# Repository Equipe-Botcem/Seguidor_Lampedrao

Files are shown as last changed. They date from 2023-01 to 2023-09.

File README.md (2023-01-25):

# Seguidor_Alpha
- Código utilizado para controle e envio de comandos do robô seguidor de linha da equipe de competição BOTCEM UFSC

## Guia de Instalação e execução:
1. Extrair o arquivo zip
2. Abrir pasta esp32_code com a extensão platform.io do VScode
3. Compilar arquivo e passa-ló para o ESP32 
4. Baixar aplicativo Line-follower.apk

## Pré-requisitos: 
1. Microcontrolador: esp32dev
2. Sistema operacional: Linux 20.04
3. IDE : Visual Studio Code
4. Framework: Arduino
	
## Autoria e constribuições:
- Esse projeto é autoria da equipe BOTCEM UFSC
	
## Fontes:
- Stack Overflow, c2022. Disponível em: <stackoverflow.com>. Acesso em: 18 de dezembro de 2022.

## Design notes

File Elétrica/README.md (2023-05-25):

# Documentação do Projeto Eletrônico do Seguidor de Linha Alpha

## 1. Projeto Elétrico

O projeto elétrico tem seu funcionamento separado em três parte: potência (alimentação) e controle.

### 1.1. Potência

O circuito de potência é composto pelos seguintes elementos:

- Bateria: LiPo 7,4V 2S 300mAh;
- Conversor de tensão Step Up: XL6009;
- Regulador de Tensão 5V: LM7805;
- Regulador de Tensão 3.3V: LM1117;
- Capacitores de Filtro: 0.22uF, 0.1uF e 10uF.
- Diodo;
- Switchs.

### 1.2. Controle

O circuito de controle é composto pelos seguintes elementos:

- Shield ESP32;
- Drivers IC: TB9051FTG Single Brushed;
- Encoders;
- Sensores de Refletância: QRE1117;
- Resistores: 47Kohns e 47ohns.

## 2. Projeto da PCB

O projeto da PCB foi desenvolvido no software KiCAD.
As dimensões da placa são: 119mm X 151mm X 1.6mm (Comprimento X Largura X Altura).
A placa é composta por duas camadas de trilhas, inferior e superior.

## 3. Medições

### 3.1. Corrente Consumida

Realizando a medição do Seguidor de Linha por uma fonte de tensão, pode-se obter as seguintes medidas de consumo:

- Ligado: 300mA;
- Velocidade Baixa: 600mA;
- Velocidade Alta: 1.5A. 

## 4. Melhorias

- Desenvolvimento de uma placa totalmente integrada.

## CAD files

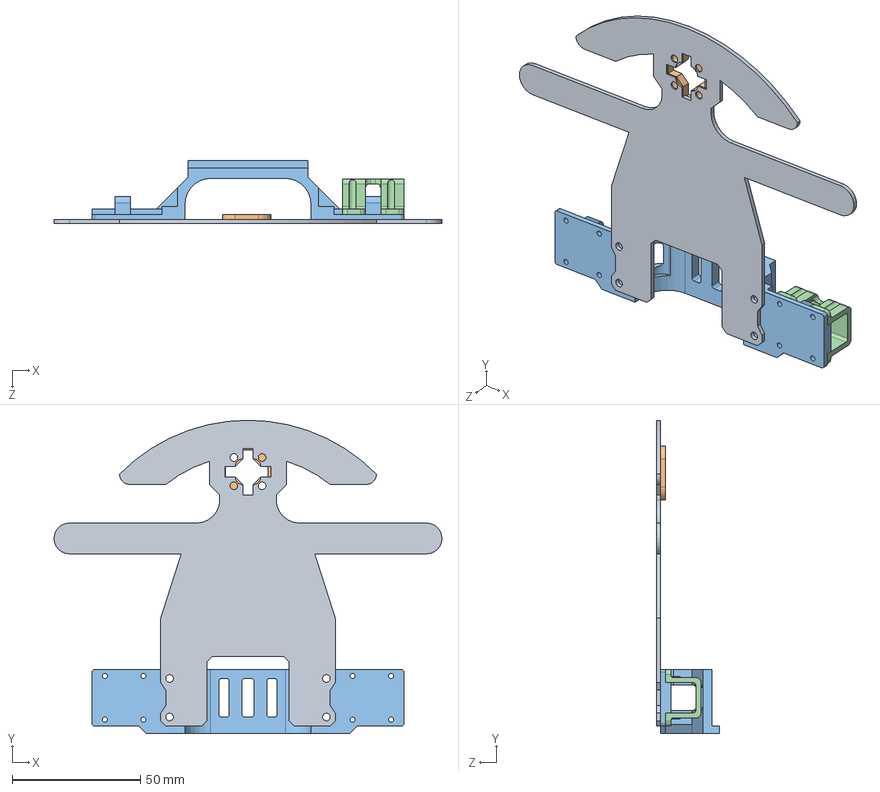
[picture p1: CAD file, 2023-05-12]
Estrutura/montagem.SLDASM
151.0 x 122.0 x 24.6 mm
placa
frontal
bateria
suporte

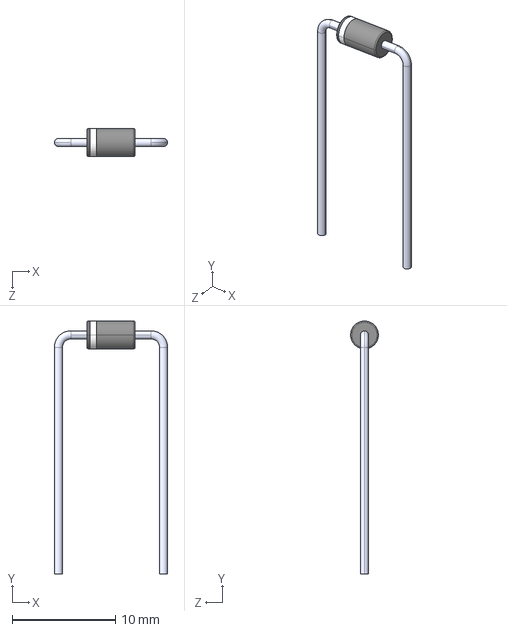
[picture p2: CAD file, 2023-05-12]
Elétrica/parts/1N5817G/1N5817G.step
10.9 x 24.5 x 2.69 mm

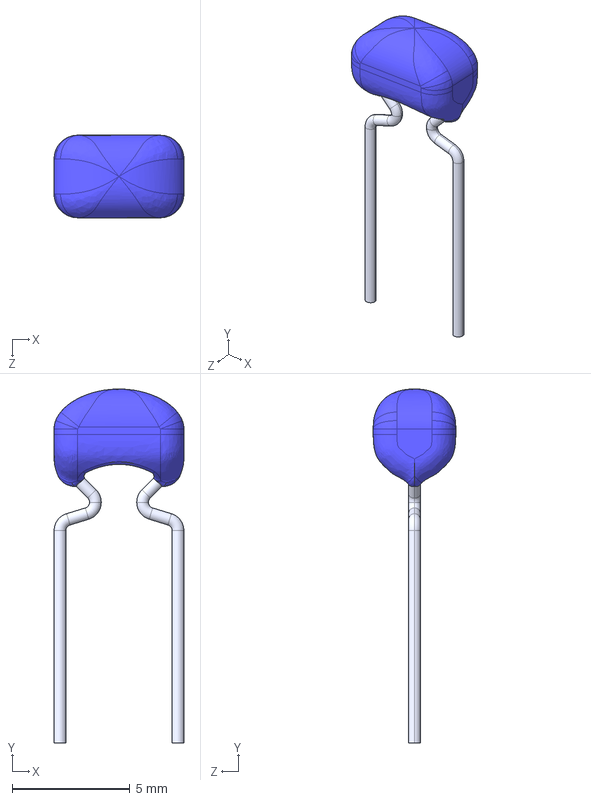
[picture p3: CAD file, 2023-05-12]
Elétrica/parts/FA16X7R2A224KNU00/FA16X7R2A224KNU00.step
5.50 x 15.0 x 3.50 mm

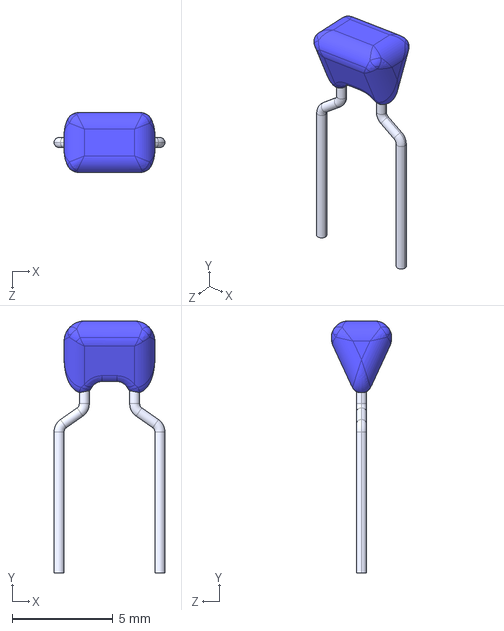
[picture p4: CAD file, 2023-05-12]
Elétrica/parts/FG24X7R1A106KRT00/FG24X7R1A106KRT00.step
5.50 x 12.5 x 3.00 mm

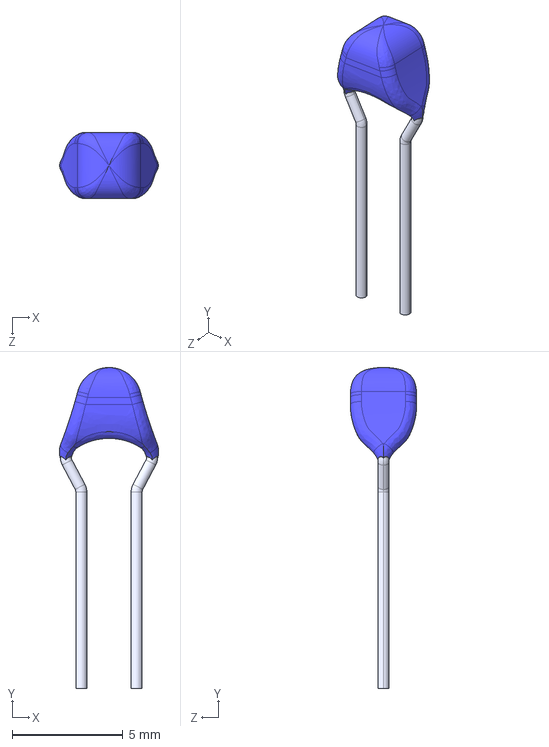
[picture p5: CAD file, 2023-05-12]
Elétrica/parts/FG24X7R2A104KNT06/FG24X7R2A104KNT06.step
4.48 x 14.5 x 3.00 mm

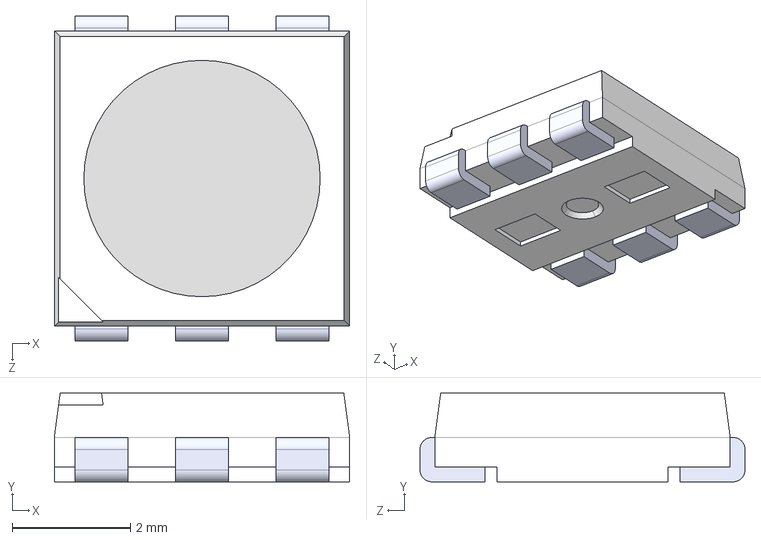
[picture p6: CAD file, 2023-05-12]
Elétrica/parts/IN-P55TATRGB/IN-P55TATRGB.step
5.00 x 1.50 x 5.50 mm

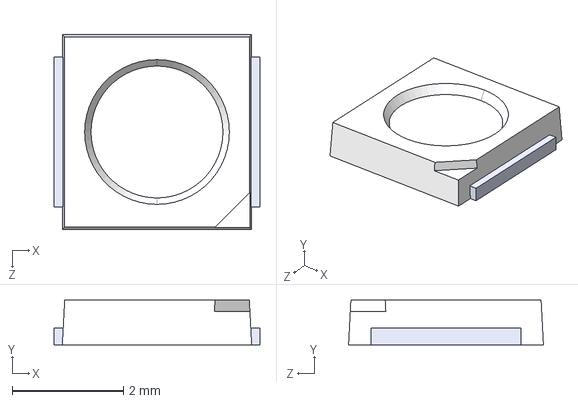
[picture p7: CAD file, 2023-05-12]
Elétrica/parts/L135-B475003500001/L135-B475003500001.step
3.70 x 0.8 x 3.50 mm

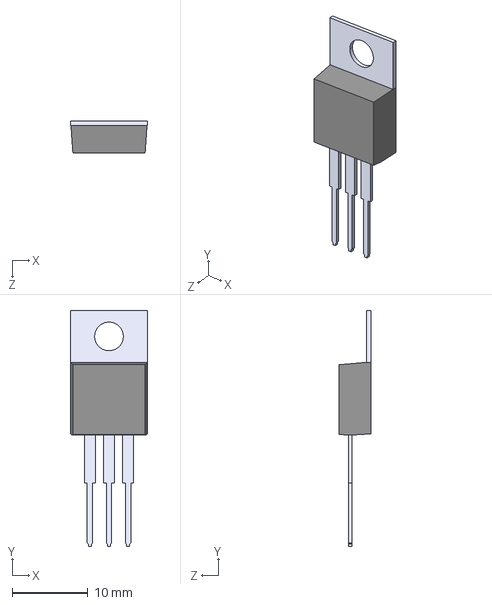
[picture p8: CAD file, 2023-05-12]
Elétrica/parts/LM1117T-3.3_NOPB/LM1117T-3.3_NOPB.step
10.2 x 31.2 x 4.20 mm

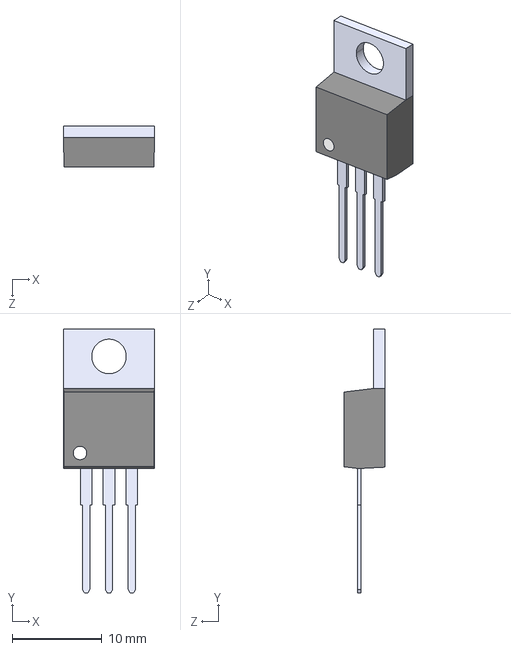
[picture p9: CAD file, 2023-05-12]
Elétrica/parts/LM7805/LM7805.step
10.2 x 29.3 x 4.57 mm

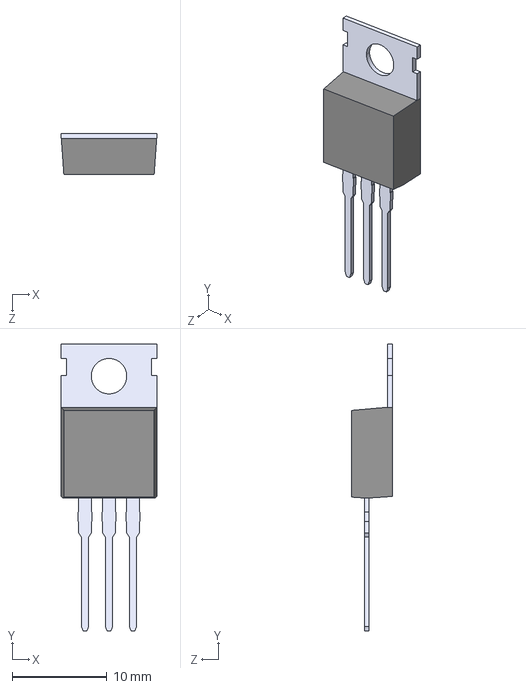
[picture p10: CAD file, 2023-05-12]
Elétrica/parts/LM7805CT_NOPB/LM7805CT_NOPB.step
10.2 x 30.3 x 4.35 mm

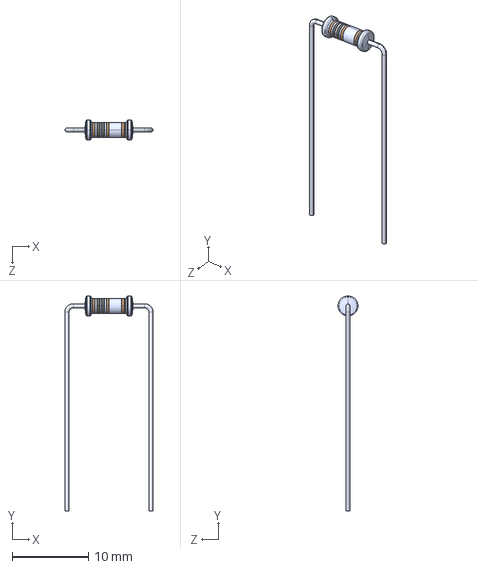
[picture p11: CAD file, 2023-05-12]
Elétrica/parts/MFR-25FBF52-61R9/MFR-25FBF52-61R9.step
11.6 x 28.1 x 2.60 mm

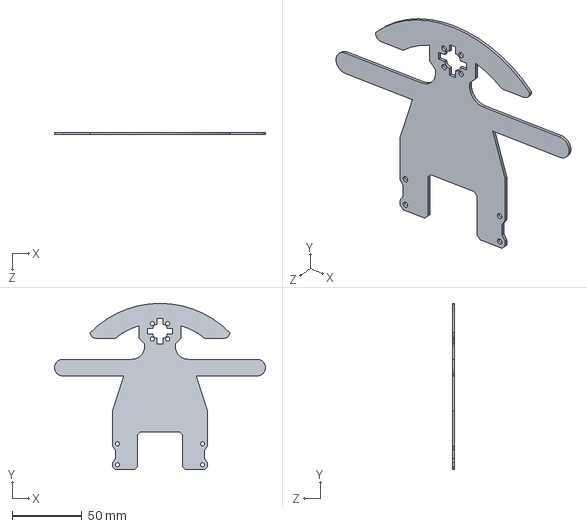
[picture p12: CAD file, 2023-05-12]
Estrutura/placa.SLDPRT
151.0 x 119.0 x 1.60 mm

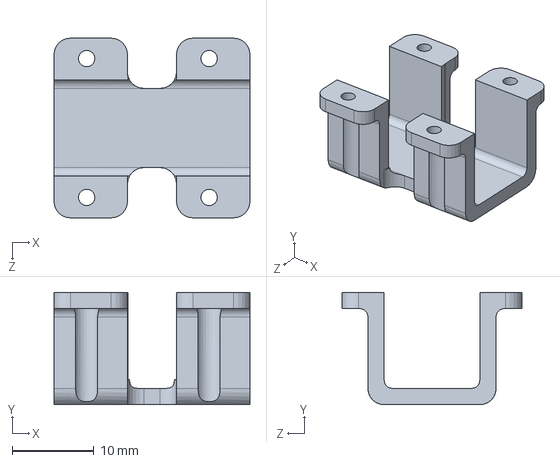
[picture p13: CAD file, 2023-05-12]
Estrutura/suporte.SLDPRT
24.0 x 13.8 x 22.0 mm

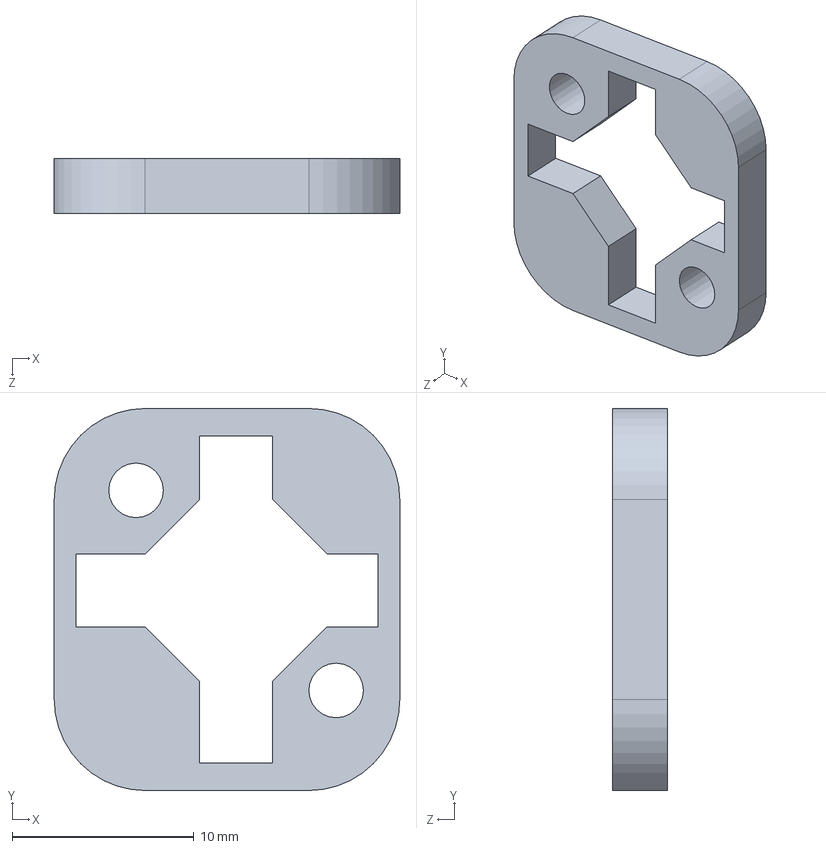
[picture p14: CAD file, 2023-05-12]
Estrutura/frontal.SLDPRT
19.0 x 21.0 x 3.00 mm

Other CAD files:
Estrutura/bateria.SLDPRT
Elétrica/parts/1622242-1/1622242-1.step

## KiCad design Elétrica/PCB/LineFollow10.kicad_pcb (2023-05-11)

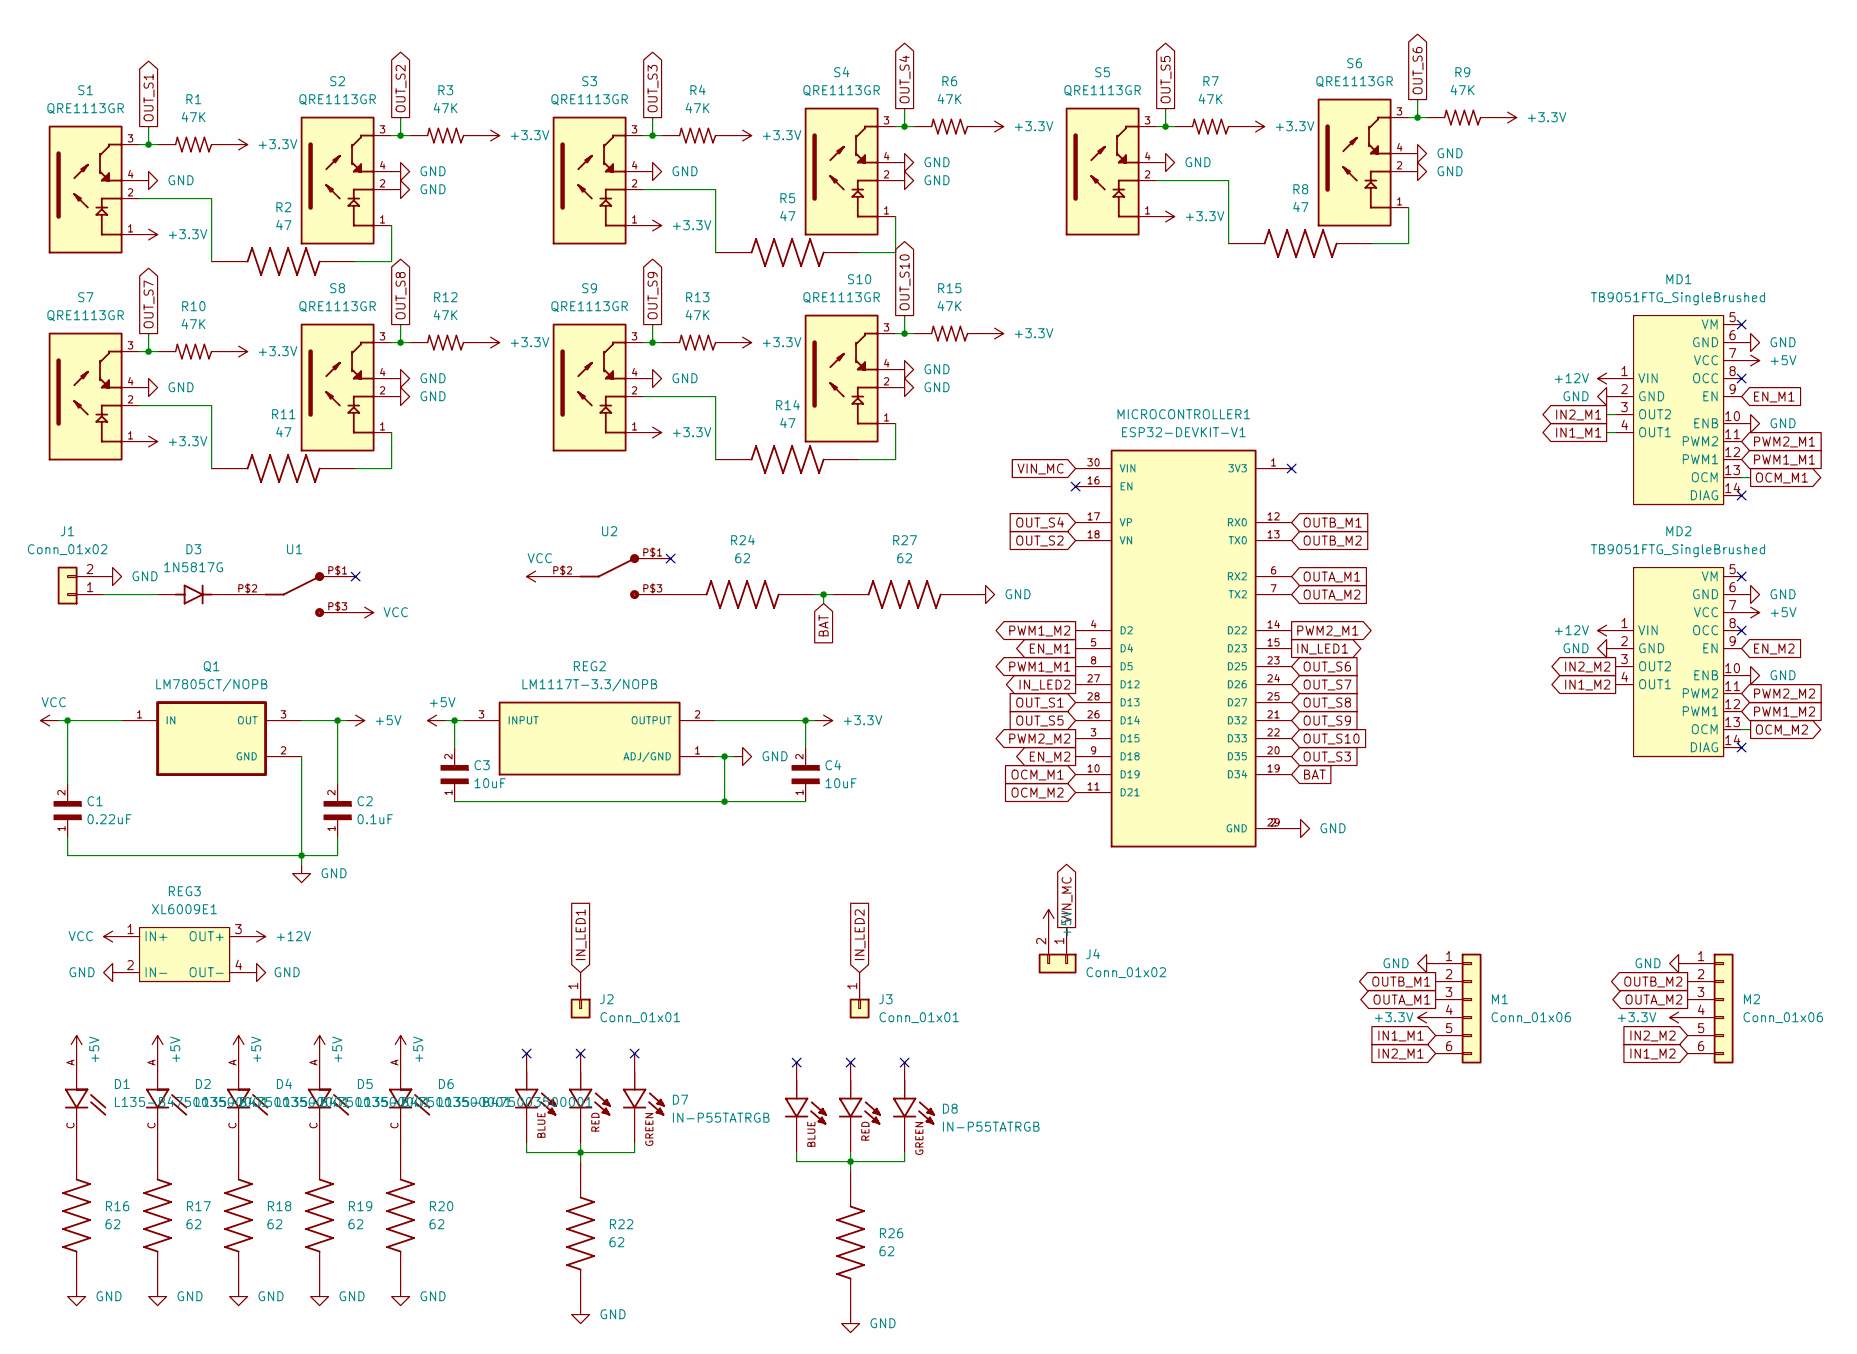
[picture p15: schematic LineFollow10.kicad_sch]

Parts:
C1: 0.22uF; CAPRB250W50L550T350H600; PARTREV 20200318
C2: 0.1uF; CAPRB500W50L450T300H550; PARTREV 20200310
C3, C4: 10uF; CAPRB500W50L450T300H550; PARTREV 20200310
D1, D2, D4, D5, D6: L135-B475003500001; LED_L135-B475003500001
D3: 1N5817G; DIOAD1036W78L470D235; PARTREV P2104
D7, D8: IN-P55TATRGB; LED_IN-P55TATRGB; PARTREV 1.0
J1: Conn_01x02; PinSocket_1x02_P2.54mm_Vertical
J2: Conn_01x01; SolderWire-0.1sqmm_1x01_D0.4mm_OD1mm
J3: Conn_01x01
J4: Conn_01x02
M1, M2: Conn_01x06; PinSocket_1x06_P2.54mm_Vertical
MD1, MD2: TB9051FTG_SingleBrushed
MICROCONTROLLER1: ESP32-DEVKIT-V1; MODULE_ESP32_DEVKIT_V1; PARTREV N/A
Q1: LM7805CT/NOPB; TO254P1054X470X2600-3; PARTREV LTR
R1, R3, R4, R6, R7, R9, R10, R12, R13, R15: 47K; RESAD640W45L370D200
R2, R5, R8, R11, R14: 47; RESAD716W44L360D186; PARTREV 11/16/2017
R16, R17, R18, R19, R20, R22, R24, R26, R27: 62; RESAD1100W55L680D260; PARTREV 201304
REG2: LM1117T-3.3/NOPB; TO254P1054X470X1955-3; PARTREV O
REG3: XL6009E1
S1, S2, S3, S4, S5, S6, S7, S8, S9, S10: QRE1113GR; SOIC180P460X187-4N; PARTREV 5
U1, U2: 0S102011MS2QN1

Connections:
+3.3V: C4.2, M1.4, M2.4, R1.1, R3.1, R4.1, R6.1, R7.1, R9.1, R10.1, R12.1, R13.1, R15.1, REG2.2 (OUTPUT), S1.1, S3.1, S5.1, S7.1, S9.1
+5V: C2.2, C3.2, D1.A, D2.A, D4.A, D5.A, D6.A, J4.2, MD1.7 (VCC), MD2.7 (VCC), Q1.3 (OUT), REG2.3 (INPUT)
+12V: MD1.1 (VIN), MD2.1 (VIN), REG3.3 (OUT+)
BAT: MICROCONTROLLER1.19 (D34), R24.1, R27.2
EN_M1: MD1.9 (EN), MICROCONTROLLER1.5 (D4)
EN_M2: MD2.9 (EN), MICROCONTROLLER1.9 (D18)
GND: C1.1, C2.1, C3.1, C4.1, J1.2, M1.1, M2.1, MD1.2 (GND), MD1.6 (GND), MD1.10 (ENB), MD2.2 (GND), MD2.6 (GND), MD2.10 (ENB), MICROCONTROLLER1.2 (GND), MICROCONTROLLER1.29 (GND), Q1.2 (GND), R16.1, R17.1, R18.1, R19.1, R20.1, R22.1, R26.1, R27.1, REG2.1 (ADJ/GND), REG3.2 (IN-), REG3.4 (OUT-), S1.4, S2.2, S2.4, S3.4, S4.2, S4.4, S5.4, S6.2, S6.4, S7.4, S8.2, S8.4, S9.4, S10.2, S10.4
IN1_M1: M1.5, MD1.4 (OUT1)
IN1_M2: M2.6, MD2.4 (OUT1)
IN2_M1: M1.6, MD1.3 (OUT2)
IN2_M2: M2.5, MD2.3 (OUT2)
IN_LED1: J2.1, MICROCONTROLLER1.15 (D23)
IN_LED2: J3.1, MICROCONTROLLER1.27 (D12)
unnamed: D1.C, R16.2
unnamed: D2.C, R17.2
unnamed: D3.A, J1.1
unnamed: D3.C, U1.P$2
unnamed: D4.C, R18.2
unnamed: D5.C, R19.2
unnamed: D6.C, R20.2
unnamed: D7.1, D7.2, D7.3, R22.2
unnamed: D8.1, D8.2, D8.3, R26.2
unnamed: R2.1, S1.2
unnamed: R2.2, S2.1
unnamed: R5.1, S3.2
unnamed: R5.2, S4.1
unnamed: R8.1, S5.2
unnamed: R8.2, S6.1
unnamed: R11.1, S7.2
unnamed: R11.2, S8.1
unnamed: R14.1, S9.2
unnamed: R14.2, S10.1
unnamed: R24.2, U2.P$3
OCM_M1: MD1.13 (OCM), MICROCONTROLLER1.10 (D19)
OCM_M2: MD2.13 (OCM), MICROCONTROLLER1.11 (D21)
OUTA_M1: M1.3, MICROCONTROLLER1.6 (RX2)
OUTA_M2: M2.3, MICROCONTROLLER1.7 (TX2)
OUTB_M1: M1.2, MICROCONTROLLER1.12 (RX0)
OUTB_M2: M2.2, MICROCONTROLLER1.13 (TX0)
OUT_S1: MICROCONTROLLER1.28 (D13), R1.2, S1.3
OUT_S2: MICROCONTROLLER1.18 (VN), R3.2, S2.3
OUT_S3: MICROCONTROLLER1.20 (D35), R4.2, S3.3
OUT_S4: MICROCONTROLLER1.17 (VP), R6.2, S4.3
OUT_S5: MICROCONTROLLER1.26 (D14), R7.2, S5.3
OUT_S6: MICROCONTROLLER1.23 (D25), R9.2, S6.3
OUT_S7: MICROCONTROLLER1.24 (D26), R10.2, S7.3
OUT_S8: MICROCONTROLLER1.25 (D27), R12.2, S8.3
OUT_S9: MICROCONTROLLER1.21 (D32), R13.2, S9.3
OUT_S10: MICROCONTROLLER1.22 (D33), R15.2, S10.3
PWM1_M1: MD1.12 (PWM1), MICROCONTROLLER1.8 (D5)
PWM1_M2: MD2.12 (PWM1), MICROCONTROLLER1.4 (D2)
PWM2_M1: MD1.11 (PWM2), MICROCONTROLLER1.14 (D22)
PWM2_M2: MD2.11 (PWM2), MICROCONTROLLER1.3 (D15)
VCC: C1.2, Q1.1 (IN), REG3.1 (IN+), U1.P$3, U2.P$2
VIN_MC: J4.1, MICROCONTROLLER1.30 (VIN)

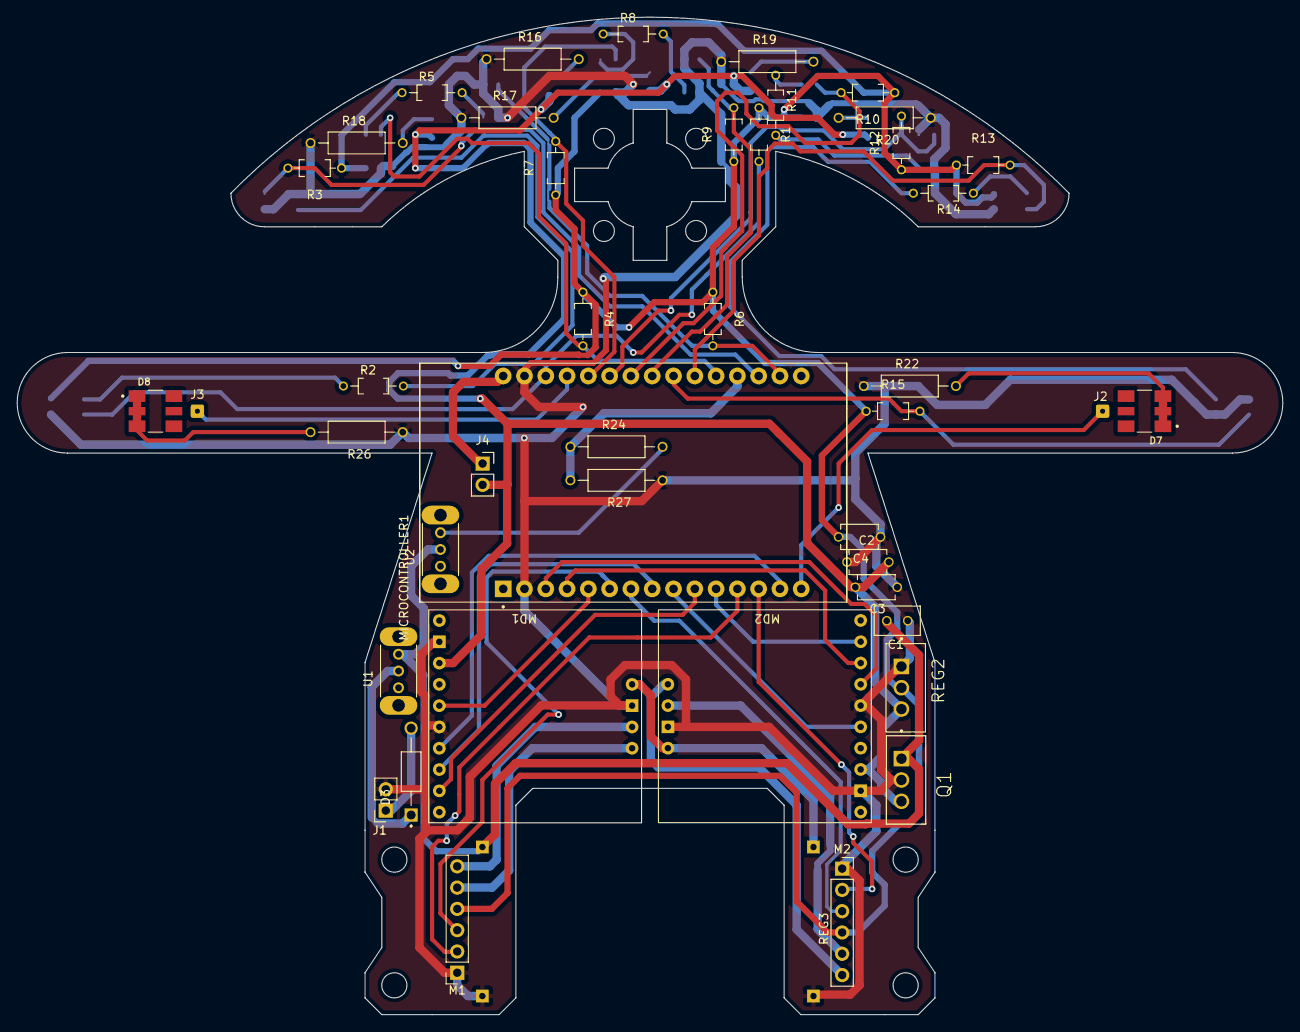
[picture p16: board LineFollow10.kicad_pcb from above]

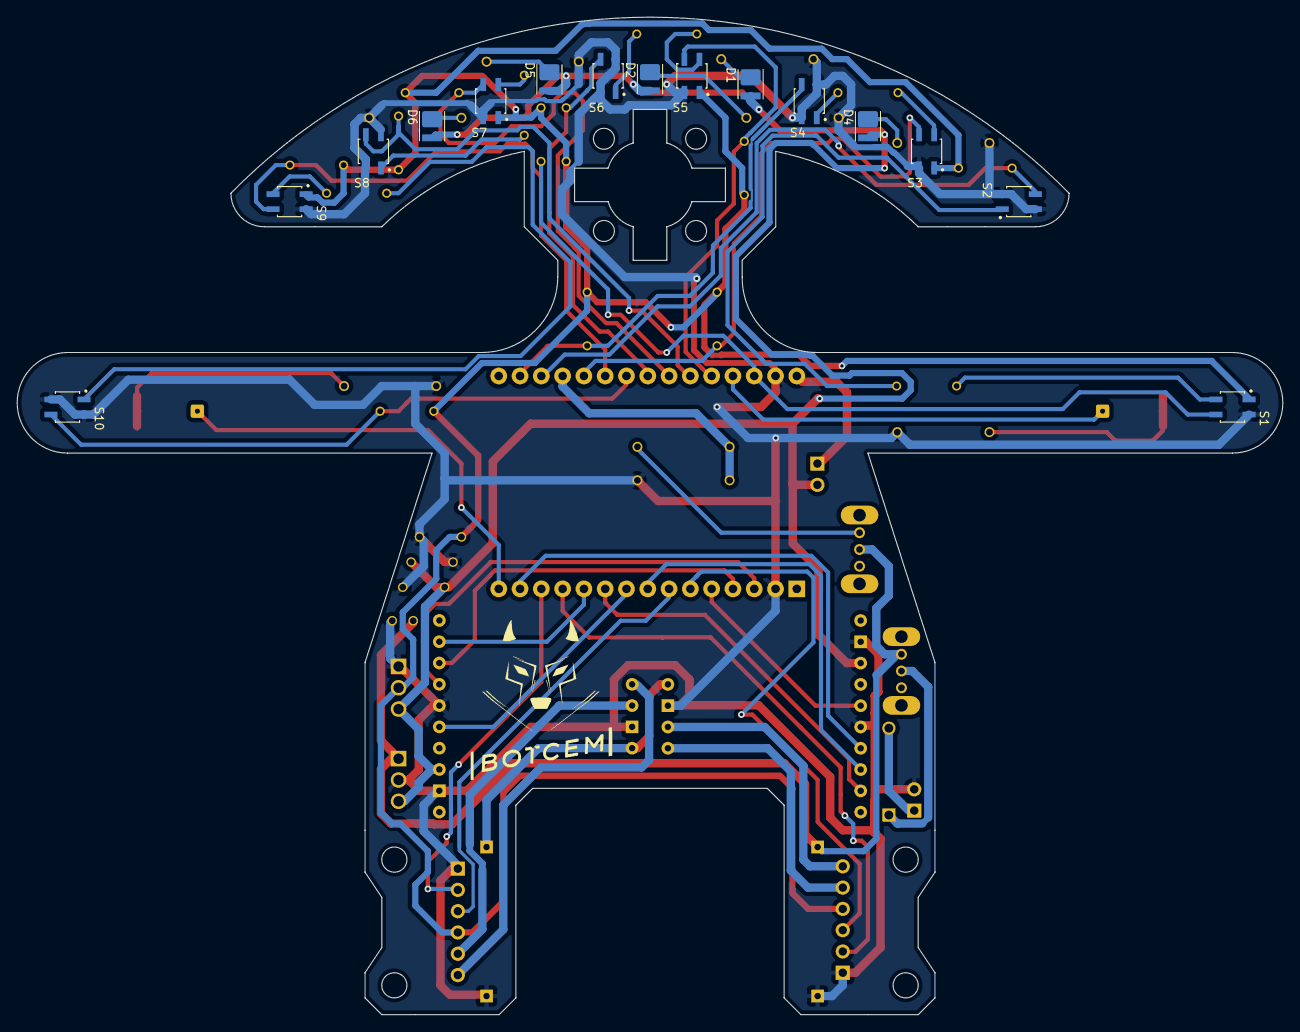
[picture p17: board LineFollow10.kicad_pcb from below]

Board: 2 copper layers, 151.0 x 119.0 mm, 64 parts (16 on the bottom side), 55 nets.

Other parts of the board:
G: LOGO; BOTCEMLOGO
REF: MountingHole_3mm
REF#2: MountingHole_2.5mm
REF#3: MountingHole_3mm

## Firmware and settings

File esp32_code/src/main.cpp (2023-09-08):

#include "Seguidor.h"

#if !defined(CONFIG_BT_ENABLED) || !defined(CONFIG_BLUEDROID_ENABLED)
#error Bluetooth is not enabled! Please run `make menuconfig` to and enable it
#endif


Seguidor seguidor = Seguidor();



void setup()
{
	Serial.begin(115200);
	seguidor.Init();
	seguidor.initBluetooth();
}


void loop(){
	
	//seguidor.teste();

	seguidor.Behavior();
	seguidor.CheckLed();

	if(seguidor.isStart()){
		seguidor.controle();

		if(!seguidor.IsOut())seguidor.stopRoutine();

		seguidor.mapeamento();	
	}
}

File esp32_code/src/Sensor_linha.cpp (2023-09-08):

#include "Sensor_linha.h"
#include "SimpleKalmanFilter.h"

SimpleKalmanFilter angleKalmanFilter(0.01, 0.01, 0.005);

Sensor_linha::Sensor_linha(){}

Sensor_linha::Sensor_linha(unsigned char* pins){
    for(unsigned i = 0; i < 8; i++){
		sensores[i] = Sensor(pins[i]);
		sensores[i].setAngle(angulos[i]);
	}
    last_read = 0;
}

void Sensor_linha::Init(){
    for(unsigned i = 0; i < tam_sensores; i++){
		sensores[i].Init();
	}
}

float Sensor_linha::getAngleRaw(){
  int j = 4;

	in = false;

	for(int i = 3; i >= 0; i--){
    if(sensores[j].Read_histerese()){
      read = mediaPond(j);
			in = true;
      break;
    } 
		if(sensores[i].Read_histerese()){
      read = mediaPond(i);
			in = true;
      break;  
    } 
		j++;
	}

	// Saiu da pista 
	if(read < 0 and in == false){
		read = -45;
	}else if(in == false)	read = 45;

	int variacao = read - last_read;

	if(abs(variacao) > 6){
		read = last_read;
	}else{
		last_read = read;
	}

	return read;
}

float Sensor_linha::getAngle(){
	return angleKalmanFilter.updateEstimate(getAngleRaw());
}

float Sensor_linha::mediaPond(int pos){
	float num;
	float den;

	if(sensores[3].Read_histerese() == HIGH and sensores[4].Read_histerese() == HIGH){
		num = sensores[3].Read_CalibradoPonderado() + sensores[4].Read_CalibradoPonderado();
		den = sensores[3].Read_Calibrado() + sensores[4].Read_Calibrado();
		return num / den;
	}

	if(pos == 0){
		num = sensores[pos].Read_CalibradoPonderado() + sensores[pos + 1].Read_CalibradoPonderado();
		den = sensores[pos].Read_Calibrado() + sensores[pos + 1].Read_Calibrado();
	}else if (pos == tam_sensores-1){
		num = sensores[pos].Read_CalibradoPonderado() + sensores[pos - 1].Read_CalibradoPonderado();
		den = sensores[pos].Read_Calibrado() + sensores[pos - 1].Read_Calibrado();
	}else{
		num = sensores[pos].Read_CalibradoPonderado() + sensores[pos - 1].Read_CalibradoPonderado() + sensores[pos + 1].Read_CalibradoPonderado();
		den = sensores[pos].Read_Calibrado() + sensores[pos - 1].Read_Calibrado() + sensores[pos + 1].Read_Calibrado();
	}
	return num / den;
}

void Sensor_linha::calibration_max(){
	for(unsigned i = 0; i < tam_sensores; i++) sensores[i].find_max();
}

void Sensor_linha::calibation_manual(){
	for(unsigned i = 0; i < tam_sensores; i++){
		sensores[i].Cmax = c_max[i];
	}
}

void Sensor_linha::testeLeitura(ReadType tipo){

	switch (tipo){
	case RAW:
		for (int i = 0; i < tam_sensores; i++){
			Serial.print("S");
			Serial.print(String(i));
			Serial.print(": ");
			Serial.print(sensores[i].Read_sensor());
			Serial.print("       ");
    }
		Serial.println();
		break;
	case CALIB:
		calibation_manual();
		for (int i = 0; i < tam_sensores; i++){
			Serial.print("S");
			Serial.print(String(i));
			Serial.print(": ");
			Serial.print(sensores[i].Read_Calibrado());
			Serial.print("       ");
		}
		Serial.println();
		break;
	case HIST:
		calibation_manual();
		for (int i = 0; i < tam_sensores; i++){
			Serial.print("S");
			Serial.print(String(i));
			Serial.print(": ");
			Serial.print(sensores[i].Read_histerese());
			Serial.print("       ");
    }
		Serial.println();
		break;

		case KALMAN:
			calibation_manual();
			Serial.print("Angle:");
			Serial.println(getAngleRaw());
			Serial.print(",");
			Serial.print("Kalman_filter:");
			Serial.println(getAngle());
		break;
	}
}

bool Sensor_linha::CheckCalibration(){
	for(unsigned i = 0; i < tam_sensores; i++){
		if(sensores[i].GetMax() == 0) return false;
	}
	return true;
}

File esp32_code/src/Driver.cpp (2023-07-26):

#include "Driver.h"
#include "Arduino.h"

Driver::Driver(){}


Driver::Driver(unsigned char *pins_dir, unsigned char *pins_esq){
    motor_esq = Motor(pins_esq[0], pins_esq[1], pins_esq[2], pins_esq[3]);
	motor_dir = Motor(pins_dir[0], pins_dir[1], pins_dir[2], pins_dir[3]);
}

void Driver::Init(){
    motor_dir.Init();
    motor_esq.Init();
}

void Driver::setVB(int vb){
    VB = vb;
}

void Driver::setMotors(int speed_esq, int speed_dir){
    motor_esq.Set_speed(speed_esq);
    motor_dir.Set_speed(speed_dir);
}

void Driver::Enable_motors_drives()
{
	motor_esq.Enable_drive();
	motor_dir.Enable_drive();
}

void Driver::Disable_motors_drives()
{
	motor_esq.Disable_drive();
	motor_dir.Disable_drive();
}

void Driver::Break(){
    motor_dir.Set_speed(0);
    motor_esq.Set_speed(0);
}

void Driver::Set_speedRot(int rot)
{
	motor_dir.Set_speed(VB + rot);
    motor_esq.Set_speed(VB - rot);
}

void Driver::teste(){
    // Move o motor para frente
    setMotors(100, 100);
    delay(5000);
    // Move o motor para trás
    setMotors(-100,-100);
    delay(5000);

    // Para o motor
    Break();
    delay(5000);
}

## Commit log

2022-08-17 Adição da classe Motor_drive
2022-08-17 Adição do diagrama de classes
2022-08-22 reestruturação para organização em classes
2022-08-23 implementação dos códigos de teste
2022-09-02 ajustes nos parametros de teste
2022-09-11 teste dos encoders concluidos
2022-09-12 código para o teste dos sensores
2022-11-05 Atualizado arquivo ini para o esp32
2022-11-05 Adição de um include com funções utilitárias
2022-11-05 Adição dos números dos pinos do esp32
2022-11-05 Refatorada classe do sensor para calibracao
2022-11-05 Adição do comportamento de histerese
2022-11-06 Refactor - Construtores sensores
2022-11-06 Refactor - Sensor.h
2022-11-06 Refactor Sensor_dir
2022-11-07 Alterando valor de retorno das funções de leitura
2022-11-08 Teste sensor
2022-11-09 Funções de teste
2022-11-09 Retirado classe S Sensor_linha
2022-11-10 Leirura do sensores ajusda
2022-11-10 Pinos do motor ajustado
2022-11-10 Ajustada resolução de leitura
2022-11-10 Behavior e teste ajustado para set
2022-11-10 Set_handler ajustado para Vmin
2022-11-10 Ajustado tempo de processamento
2023-01-25 Atualizando nomes de pastas
2023-03-26 Fix bugs calibration
2023-04-18 Add config leds
2023-04-19 Add teste motor
2023-04-19 Add calibration values
2023-04-20 Invert pinos motor 1
    [Seguidor.h]
2023-05-11 Adicionando os arquivos do projeto da PCB
    [LineFollow10.kicad_pcb, LineFollow10.kicad_sch]
2023-05-12 Adicionando os componentes do projeto
    [1622242-1.step, 1N5817G.step, FA16X7R2A224KNU00.step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]
2023-05-12 Adicionando os arquivos do SolidWorks da estrutura
    [bateria.SLDPRT, frontal.SLDPRT, montagem.SLDASM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]
2023-05-25 Add kalman filter lib and control
2023-05-25 Fix return to line
    [Seguidor.cpp, main.cpp]
2023-05-31 Add kalman filter
2023-06-07 Kalman filter visualization
2023-07-11 Add CLass Sensor_linha
2023-07-11 Add teste sensores
2023-07-13 Add PID digital
2023-07-21 Recebimento de parâmetros
2023-07-23 Fix Cmin and ENCH calibration
    [Seguidor.cpp, Seguidor.h, Sensor_linha.cpp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]
2023-09-10 Consertado print
